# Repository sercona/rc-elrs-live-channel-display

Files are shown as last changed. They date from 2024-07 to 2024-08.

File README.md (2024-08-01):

# Arduino Display of ELRS Channel Values

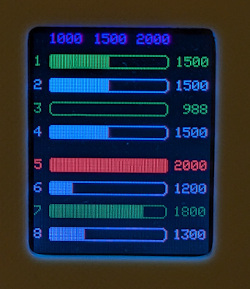
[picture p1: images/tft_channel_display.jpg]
display


* Purpose:
  - For remote control (RC) pilots who want to see what the values being sent by their transmitter (handset) are.
  - ExpressLRS (ELRS) is a new RC protocol that is becoming the dominant control protocol in the hobby.
  - To bring-up (build, fix, modify) flight controllers and other related hardware, its useful to have something that can see actual values in realtime.
  - ELRS uses the concept of 'binding' (roughly similar to bluetooth) to link stations; to view an ELRS transmitter stream, you must be using the same 'binding phrase' as the transmitter.

* Demo video: https://github.com/sercona/rc-elrs-live-channel-display/raw/main/images/elrs-controller-demo1.mp4

* Based on some demo code from the expresslrs project

* Hardware needed:
  - ESP8266 (eg, wemos d1 mini)
  - elrs serial receiver (as normally used in a quadcopter, etc)
  - SPI TFT display ST7735 (https://www.amazon.com/gp/product/B0C2HNVSWV/)
  - 3d printed case
  
* Software:
  - Import the code as you normally would with the arduino IDE
  - Flash your esp8266 over its usb serial port.  IMPORTANT: remove the elrs receiver when you serial-flash your ESP chip.
  - Once flash is done, the elrs receiver module can now be plugged in; with its 'tx' pin (this is the data OUT from the elrs module) connected to the 'rx' pin on the only serial uart of the ESP8266. 

* Connections:
  - Only 3 wires are needed for elrs listening; the data wire (to the RX gpio of the ESP), and 5v power and ground.
  - Power the ESP chip, tft display and elrs module from an external 5v supply.
  - If you need to reflash the ESP, remember to remove the elrs (or put a switch on the single data line) before you flash and reconnect after flash is done.
  - Wiring gpio pins can be found in src/esp_tft_elrs_decoder.h
    - TFT pins on wemos d1 mini: (D4=SPI_CS, D5=SPI_CLK, D6=SPI_MISO, D7=SPI_MOSI, D8=SPI_CS)
    - TFT will need backlight; wire that to 5v.  RESET wire on tft goes to RESET on ESP chip.  Note, TFT vcc is 3.3v not 5v!
  
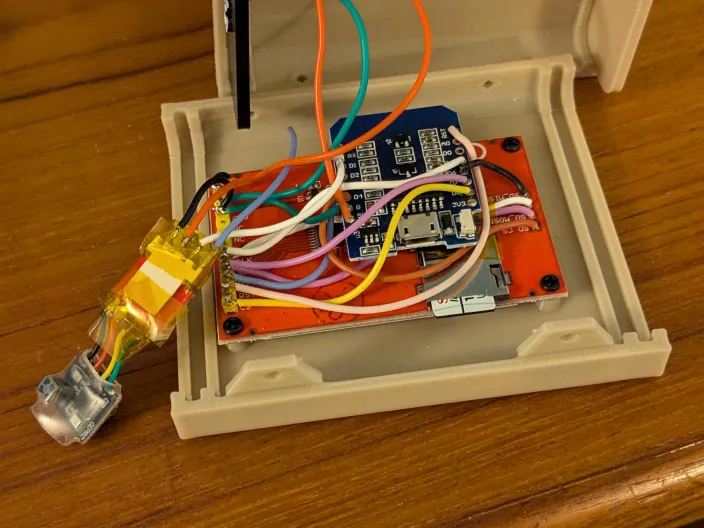
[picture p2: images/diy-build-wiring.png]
wiring
  

* 3D print STL files in the stl folder
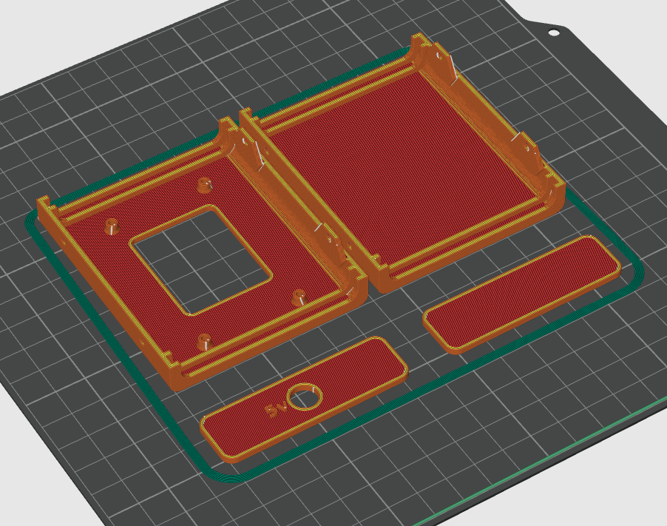
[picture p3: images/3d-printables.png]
3dprints


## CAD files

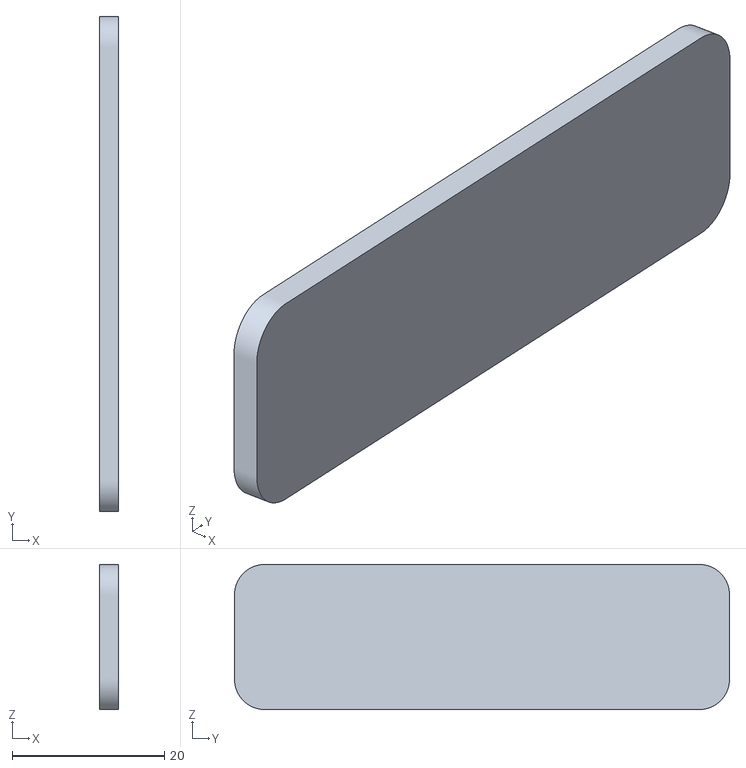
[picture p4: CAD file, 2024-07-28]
stl/rc-elrs-chan-display-blank-bottom-panel.stl
2.45 x 65.1 x 19.1

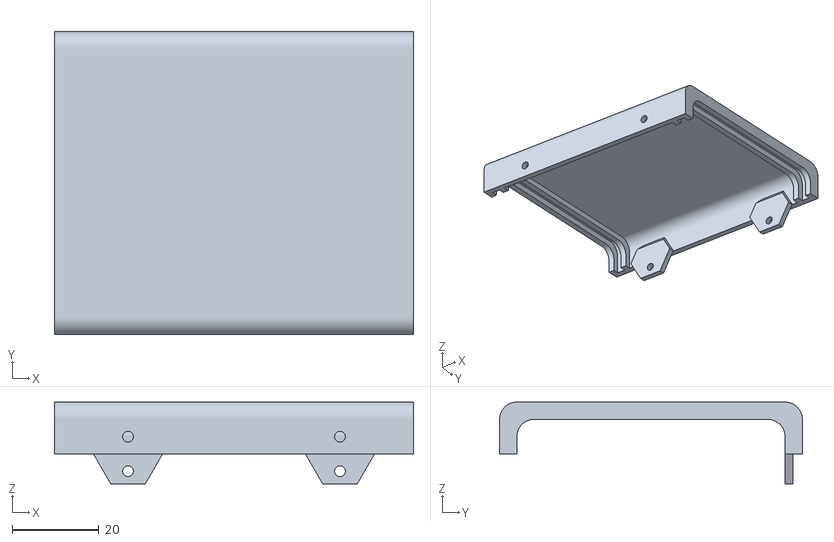
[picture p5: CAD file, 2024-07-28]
stl/rc-elrs-chan-display-back.stl
83.0 x 70.0 x 18.9

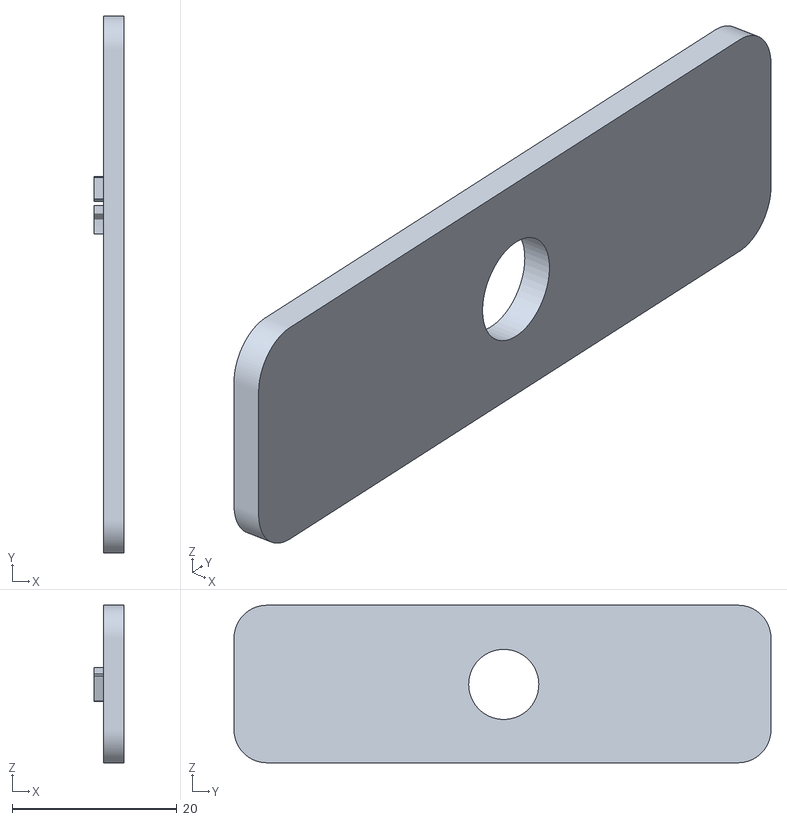
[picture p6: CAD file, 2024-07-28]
stl/rc-elrs-chan-display-5v-hole-top-panel.stl
3.60 x 65.1 x 19.1

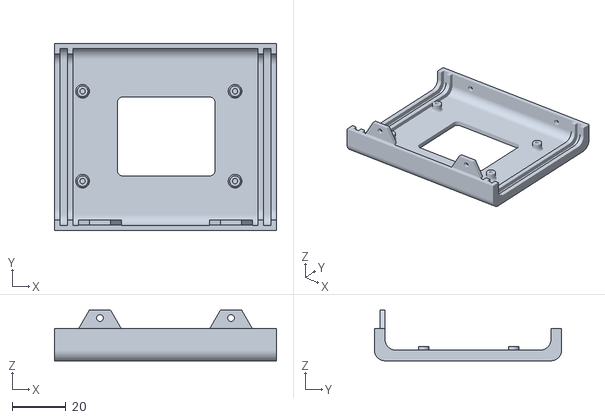
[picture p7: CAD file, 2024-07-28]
stl/rc-elrs-chan-display-front.stl
83.0 x 70.0 x 18.9

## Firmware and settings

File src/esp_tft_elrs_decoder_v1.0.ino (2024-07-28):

/*
  esp_tft_elrs_decoder

  arduino esp8266 (also can work with esp32) that receives a 'crossfire' (elrs) serial stream
  from a common, standard elrs serial receiver module and decodes it into 8 channels
  that are displayed separately on a tft display.

  elrs code based on open code from the 'express LRS' project.

  (c) 2024 linux-works labs
*/

const char *MY_INO_FILE = __FILE__;  // capture the .ino filename and save it

#include "esp_tft_elrs_decoder.h"             // our main include


//
// library classes
//

TFT_eSPI tft = TFT_eSPI();                   // tft display (one instance)

//
// app-specific classes
//

UI_TFT      gui;               // GUI class for this app


// controller rx values (1-8, ignore 0)
int chan_values[9];
int last_chan_values[9];


#define PIN_LED    2   // D4
#define LED_OFF    1
#define LED_ON     0


// remove any previous def
#ifdef CRSF_BAUDRATE
#undef CRSF_BAUDRATE
#endif

#define CRSF_BAUDRATE 420000  // this is ok to use on both esp8266 and esp32

CrsfSerial crsf(Serial, CRSF_BAUDRATE);   // using the ONLY hardware serial on esp8266 (so remove your elrs rx if you have to re-flash the esp)



void packetChannels (void)
{
  for (int chan = 1; chan <= 8; chan++) {
    chan_values[chan] = crsf.getChannel(chan);
  }
}


void crsfLinkUp (void)
{
  digitalWrite(PIN_LED, 0);

#if 0
  // make link-up sound
  for (int i = 0; i < 3; i++) {
    digitalWrite(PIN_BUZZER, 0);  // ground the pin, to turn the buzzer on
    delay(50);
    digitalWrite(PIN_BUZZER, 1);  // raise the pin, to turn the buzzer off
    delay(50);
  }
#endif
}


void crsfLinkDown (void)
{
  digitalWrite(PIN_LED, 1);

  // failsafe middle values
  for (int i = 0; i < 9; i++) {
    chan_values[i] = 1500;
    last_chan_values[i] = -1;  // force a change-detect on first loop
  }

#if 0
  // make link-down sound
  for (int i = 0; i < 5; i++) {
    digitalWrite(PIN_BUZZER, 0);  // ground the pin, to turn the buzzer on
    delay(50);
    digitalWrite(PIN_BUZZER, 1);  // raise the pin, to turn the buzzer off
    delay(50);
  }
#endif
}



void setup (void)
{
  pinMode(LED_BUILTIN, OUTPUT);
  digitalWrite(LED_BUILTIN, 1);  // turn off led


  //
  // setup serial tty out (or not)
  //

#ifdef VERBOSE_SERIAL_TTY
  Serial.setDebugOutput(true);
  Serial.begin(115200);
  while (!Serial) {
    delay(100);      // will pause Zero, Leonardo, etc until serial console opens
  }
#else
  Serial.setDebugOutput(false);
#endif


  // init channels
  for (int i = 0; i < 9; i++) {
    chan_values[i] = 1500;
    last_chan_values[i] = -1;  // force a change-detect on first loop
  }

  // init color display
  tft.init();
  tft.setRotation(0);
  tft.setTextSize(1);

  gui.graphic_splash_screen_and_init();

  // proper way to clear the screen, it seems
  tft.fillRect(0, 0, TFT_SIZE_W, TFT_SIZE_H, TFT_BLACK);

  // initial tft display field headings
  gui.refresh_screen();


  // start the crossfire class
  crsf.begin();

  // attach the channels callback
  crsf.onPacketChannels = &packetChannels;
  crsf.onLinkUp = &crsfLinkUp;
  crsf.onLinkDown = &crsfLinkDown;
}




//
// the main arduino loop
//

void loop (void)
{
  static int last_millis = 0;


  // get channel values from receiver
  crsf.loop();
  yield();


  // run the tft screen update on a timer
  if ((millis() - last_millis) > 20) {
    gui.update_bargraphs();
    yield();

    last_millis = millis();   // record when we finished, for more even spacing between graph displays
  }

} // loop




// end esp_tft_elrs_decoder.ino

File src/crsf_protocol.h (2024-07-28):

/*
 * crsf_protocol.h
 */

#pragma once

#include <stdint.h>

#if !defined(PACKED)
#define PACKED __attribute__((packed))
#endif

#define CRSF_BAUDRATE           420000
#define CRSF_NUM_CHANNELS 16
#define CRSF_CHANNEL_VALUE_MIN  172 // 987us - actual CRSF min is 0 with E.Limits on
#define CRSF_CHANNEL_VALUE_1000 191
#define CRSF_CHANNEL_VALUE_MID  992
#define CRSF_CHANNEL_VALUE_2000 1792
#define CRSF_CHANNEL_VALUE_MAX  1811 // 2012us - actual CRSF max is 1984 with E.Limits on
#define CRSF_CHANNEL_VALUE_SPAN (CRSF_CHANNEL_VALUE_MAX - CRSF_CHANNEL_VALUE_MIN)
#define CRSF_ELIMIT_US_MIN         891   // microseconds for CRSF=0 (E.Limits=ON)
#define CRSF_ELIMIT_US_MAX         2119  // microseconds for CRSF=1984
#define CRSF_MAX_PACKET_SIZE 64 // max declared len is 62+DEST+LEN on top of that = 64
#define CRSF_MAX_PAYLOAD_LEN (CRSF_MAX_PACKET_SIZE - 4) // Max size of payload in [dest] [len] [type] [payload] [crc8]

// Clashes with CRSF_ADDRESS_FLIGHT_CONTROLLER
#define CRSF_SYNC_BYTE 0XC8

enum {
  CRSF_FRAME_LENGTH_ADDRESS = 1, // length of ADDRESS field
  CRSF_FRAME_LENGTH_FRAMELENGTH = 1, // length of FRAMELENGTH field
  CRSF_FRAME_LENGTH_TYPE = 1, // length of TYPE field
  CRSF_FRAME_LENGTH_CRC = 1, // length of CRC field
  CRSF_FRAME_LENGTH_TYPE_CRC = 2, // length of TYPE and CRC fields combined
  CRSF_FRAME_LENGTH_EXT_TYPE_CRC = 4, // length of Extended Dest/Origin, TYPE and CRC fields combined
  CRSF_FRAME_LENGTH_NON_PAYLOAD = 4, // combined length of all fields except payload
};

enum {
  CRSF_FRAME_GPS_PAYLOAD_SIZE = 15,
  CRSF_FRAME_BATTERY_SENSOR_PAYLOAD_SIZE = 8,
  CRSF_FRAME_LINK_STATISTICS_PAYLOAD_SIZE = 10,
  CRSF_FRAME_RC_CHANNELS_PAYLOAD_SIZE = 22, // 11 bits per channel * 16 channels = 22 bytes.
  CRSF_FRAME_ATTITUDE_PAYLOAD_SIZE = 6,
};

typedef enum
{
  CRSF_FRAMETYPE_GPS = 0x02,
  CRSF_FRAMETYPE_BATTERY_SENSOR = 0x08,
  CRSF_FRAMETYPE_LINK_STATISTICS = 0x14,
  CRSF_FRAMETYPE_OPENTX_SYNC = 0x10,
  CRSF_FRAMETYPE_RADIO_ID = 0x3A,
  CRSF_FRAMETYPE_RC_CHANNELS_PACKED = 0x16,
  CRSF_FRAMETYPE_ATTITUDE = 0x1E,
  CRSF_FRAMETYPE_FLIGHT_MODE = 0x21,
  // Extended Header Frames, range: 0x28 to 0x96
  CRSF_FRAMETYPE_DEVICE_PING = 0x28,
  CRSF_FRAMETYPE_DEVICE_INFO = 0x29,
  CRSF_FRAMETYPE_PARAMETER_SETTINGS_ENTRY = 0x2B,
  CRSF_FRAMETYPE_PARAMETER_READ = 0x2C,
  CRSF_FRAMETYPE_PARAMETER_WRITE = 0x2D,
  CRSF_FRAMETYPE_COMMAND = 0x32,
  // MSP commands
  CRSF_FRAMETYPE_MSP_REQ = 0x7A,   // response request using msp sequence as command
  CRSF_FRAMETYPE_MSP_RESP = 0x7B,  // reply with 58 byte chunked binary
  CRSF_FRAMETYPE_MSP_WRITE = 0x7C, // write with 8 byte chunked binary (OpenTX outbound telemetry buffer limit)
} crsf_frame_type_e;

typedef enum
{
  CRSF_ADDRESS_BROADCAST = 0x00,
  CRSF_ADDRESS_USB = 0x10,
  CRSF_ADDRESS_TBS_CORE_PNP_PRO = 0x80,
  CRSF_ADDRESS_RESERVED1 = 0x8A,
  CRSF_ADDRESS_CURRENT_SENSOR = 0xC0,
  CRSF_ADDRESS_GPS = 0xC2,
  CRSF_ADDRESS_TBS_BLACKBOX = 0xC4,
  CRSF_ADDRESS_FLIGHT_CONTROLLER = 0xC8,
  CRSF_ADDRESS_RESERVED2 = 0xCA,
  CRSF_ADDRESS_RACE_TAG = 0xCC,
  CRSF_ADDRESS_RADIO_TRANSMITTER = 0xEA,
  CRSF_ADDRESS_CRSF_RECEIVER = 0xEC,
  CRSF_ADDRESS_CRSF_TRANSMITTER = 0xEE,
} crsf_addr_e;

typedef struct crsf_header_s
{
  uint8_t device_addr; // from crsf_addr_e
  uint8_t frame_size;  // counts size after this byte, so it must be the payload size + 2 (type and crc)
  uint8_t type;        // from crsf_frame_type_e
  uint8_t data[0];
} PACKED crsf_header_t;

typedef struct crsf_channels_s
{
  unsigned ch0 : 11;
  unsigned ch1 : 11;
  unsigned ch2 : 11;
  unsigned ch3 : 11;
  unsigned ch4 : 11;
  unsigned ch5 : 11;
  unsigned ch6 : 11;
  unsigned ch7 : 11;
  unsigned ch8 : 11;
  unsigned ch9 : 11;
  unsigned ch10 : 11;
  unsigned ch11 : 11;
  unsigned ch12 : 11;
  unsigned ch13 : 11;
  unsigned ch14 : 11;
  unsigned ch15 : 11;
} PACKED crsf_channels_t;

typedef struct crsfPayloadLinkstatistics_s
{
  uint8_t uplink_RSSI_1;
  uint8_t uplink_RSSI_2;
  uint8_t uplink_Link_quality;
  int8_t uplink_SNR;
  uint8_t active_antenna;
  uint8_t rf_Mode;
  uint8_t uplink_TX_Power;
  uint8_t downlink_RSSI;
  uint8_t downlink_Link_quality;
  int8_t downlink_SNR;
} crsfLinkStatistics_t;

typedef struct crsf_sensor_battery_s
{
  uint32_t voltage : 16;  // V * 10 big endian
  uint32_t current : 16;  // A * 10 big endian
  uint32_t capacity : 24; // mah big endian
  uint32_t remaining : 8; // %
} PACKED crsf_sensor_battery_t;

typedef struct crsf_sensor_gps_s
{
  int32_t latitude;   // degree / 10,000,000 big endian
  int32_t longitude;  // degree / 10,000,000 big endian
  uint16_t groundspeed;  // km/h / 10 big endian
  uint16_t heading;   // GPS heading, degree/100 big endian
  uint16_t altitude;  // meters, +1000m big endian
  uint8_t satellites; // satellites
} PACKED crsf_sensor_gps_t;

#if !defined(__linux__)
static inline uint16_t htobe16(uint16_t val)
{
#if (__BYTE_ORDER__ == __ORDER_BIG_ENDIAN__)
  return val;
#else
  return __builtin_bswap16(val);
#endif
}

static inline uint16_t be16toh(uint16_t val)
{
#if (__BYTE_ORDER__ == __ORDER_BIG_ENDIAN__)
  return val;
#else
  return __builtin_bswap16(val);
#endif
}

static inline uint32_t htobe32(uint32_t val)
{
#if (__BYTE_ORDER__ == __ORDER_BIG_ENDIAN__)
  return val;
#else
  return __builtin_bswap32(val);
#endif
}

static inline uint32_t be32toh(uint32_t val)
{
#if (__BYTE_ORDER__ == __ORDER_BIG_ENDIAN__)
  return val;
#else
  return __builtin_bswap32(val);
#endif
}
#endif

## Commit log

2024-07-28 added video and build wiring image
2024-07-28 3d print files
    [rc-elrs-chan-display-5v-hole-top-panel.stl, rc-elrs-chan-display-back.stl, rc-elrs-chan-display-blank-bottom-panel.stl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]
2024-07-28 Update README.md
    wiring details added
2024-07-29 Update README.md
    clarify wiring
2024-07-29 Update README.md
    typo spi
